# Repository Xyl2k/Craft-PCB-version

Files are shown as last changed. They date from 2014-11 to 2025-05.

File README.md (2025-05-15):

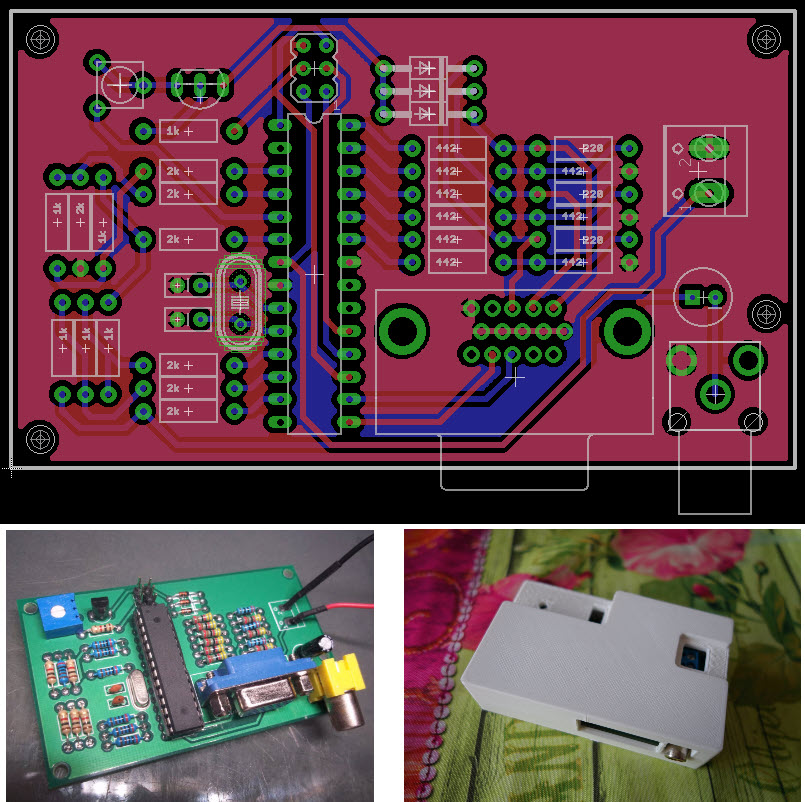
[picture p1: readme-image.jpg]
Craft


# CRAFT AVR Demo — Custom PCB and 3D Enclosure

This repository contains a custom **double-layer PCB** design and a **3D-printable enclosure** for running the [CRAFT demo](http://www.linusakesson.net/scene/craft/) by Linus Åkesson on an **ATmega88-20PU** microcontroller.

The project is developed in **Autodesk EAGLE** for the PCB layout and includes an **STL enclosure model** designed for FDM 3D printing.

---

## 📦 Contents

- `eagle/`: EAGLE schematic (`.sch`) and board layout (`.brd`)
- `enclosure/`: 3D enclosure model (`.stl`)
- `firmware/`: Precompiled HEX file and Flipper Zero-compatible firmware folder
- `README.md`: Project documentation

---

## ⚙️ Features

- Runs the original CRAFT demo at **20 MHz**
- Audio synthesized in real-time by the ATmega88
- Double-layer PCB with clear silkscreen labeling
- Compact size with mounting holes for enclosure
- Powered via ISP header or screw terminal in 3.3 volts

---

## 📋 Bill of Materials (BOM)

| Qty | Component | Value/Type |
|-----|---|---|
| x7  | Resistor | 2 kΩ |
| x6  | Resistor | 1 kΩ |
| x9  | Resistor | 442 Ω |
| x3  | Resistor | 220 Ω |
| x2  | Capacitor | 22 pF |
| x1  | Capacitor | 10 µF |
| x3  | Diode | 1N4148 |
| x1  | Transistor | BC560C |
| x1  | Trimmer Potentiometer  | 1 kΩ |
| x1  | Microcontroller | ATmega88-20PU |
| x1  | Crystal Oscillator | 20 MHz |
| x1  | VGA Socket (Female) | Through-hole |
| x1  | RCA Socket (Female) | Through-hole |
| x1  | Screw Terminal | 2-pin |

---

## 🖨️ Enclosure

- Format: `.stl` for 3D printing
- Designed for FDM printers (0.4 mm nozzle recommended)
- Includes cutouts for VGA, RCA, power terminal, and ISP pins
- Snap-fit
- PCB enclosure case.STL need to be printed with support.

---

## 🛠️ Flashing the Firmware

The `firmware/` folder includes:

- `flash.hex` — Precompiled firmware for ATmega88-20PU
- `AVR Flasher/` — Folder structure compatible with **Flipper Zero**

### 🔧 Flashing with Flipper Zero

1. Copy the content of `AVR Flasher/` folder to your Flipper Zero's SD card in (`/apps_data/avr_isp/`).
2. Connect your Flipper to the CRAFT PCB via the ISP header.
3. Open the [**AVR Flasher**](https://lab.flipper.net/apps/avr_isp) app on your Flipper.
4. Select Craft_pcb.avr firmware and flash it directly to the ATmega88.

---

## 🧠 Credits

- **Original CRAFT demo** by [Linus Åkesson](http://www.linusakesson.net/)
- **PCB and enclosure design** by myself for my hackerspace.

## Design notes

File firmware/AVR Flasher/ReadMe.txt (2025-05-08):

If you have a flipper zero you can simply download this app: https://lab.flipper.net/apps/avr_isp
Then drop in your SD card into folder: apps_data/avr_isp
- Craft_pcb.avr
- Craft_pcb_eeprom.hex
- Craft_pcb_flash.hex

Connect your flipper zero gpio to the SPI bus on the PCB and flash the ATMega88 using the app.

       FLIPPER ZERO --- PCB ---               PCB --- FLIPPER ZERO
                                  ______
          PIN 11  --  GND -----  | x  x |  ----> RST  -- PIN 06
          PIN 02  --  MOSI <---  | x  x    ----> SCK  -- PIN 05
          PIN 09  --  VCC -----  | x  x |  <---- MISO -- PIN 03
                                  ------

                                .---__---.     
                          RESET |        | PC5 
                                |        |     
                            PD0 |        | PC4 
                                |        |     
                            PD1 |        | PC3 
                                |        |     
                            PD2 |        | PC2 
                                |        |     
                           OC2B |        | PC1 
                                |        |     
                            PD4 |        | PC0 
                                |        |     
                            VCC |        | GND 
                                |        |     
                            GND |        | AREF
                                |        |     
                          XTAL1 |        | AVCC
                                |        |     
                          XTAL2 |        | SCK 
                                |        |     
                            PD5 |        | MISO
                                |        |     
                            PD6 |        | MOSI
                                |        |
                            PD7 |        | OC1B
                                |        |
                            PB0 |        | PB1 
                                `--------'

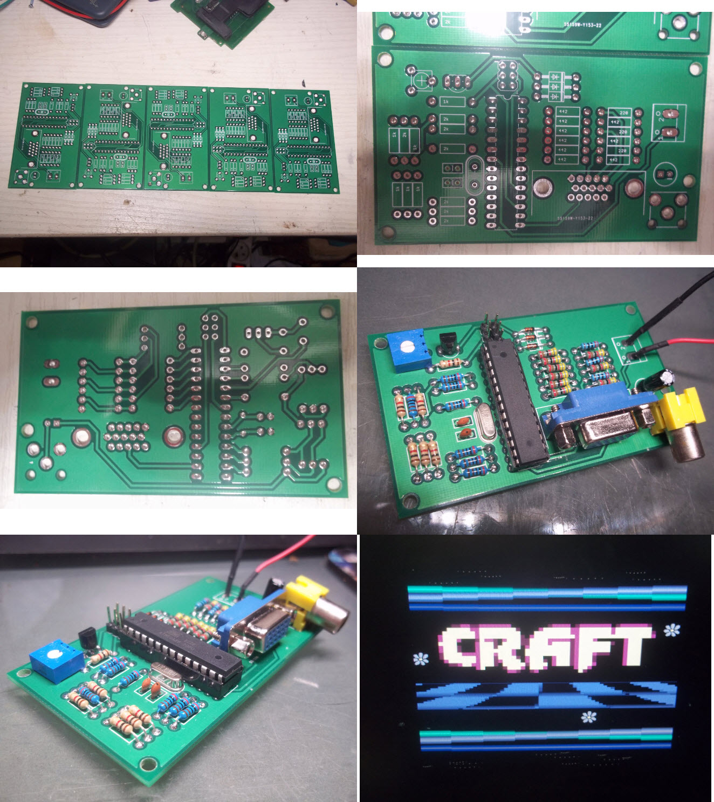
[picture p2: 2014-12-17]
PCB.jpg

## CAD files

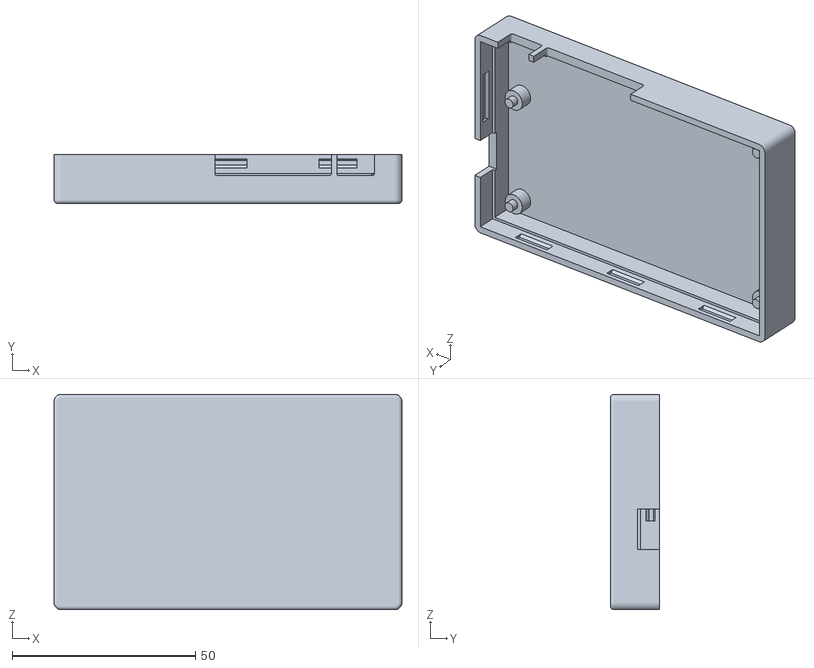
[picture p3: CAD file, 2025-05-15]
enclosure/PCB enclosure base.STL
95.1 x 13.4 x 58.9

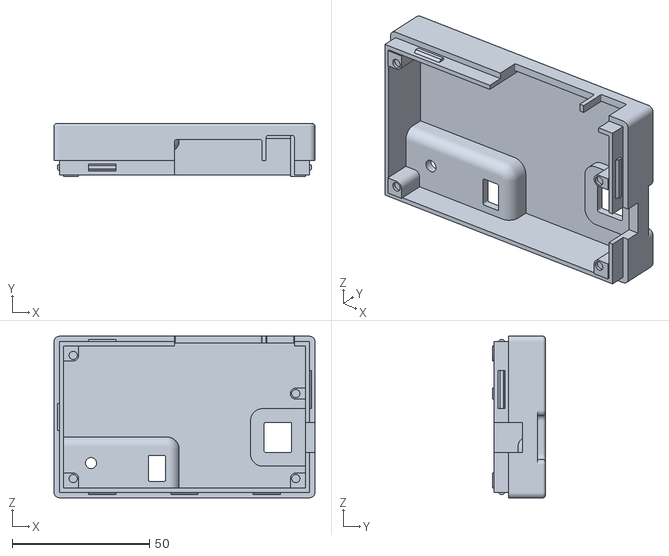
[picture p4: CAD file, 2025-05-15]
enclosure/PCB enclosure case.STL
95.1 x 19.3 x 58.9

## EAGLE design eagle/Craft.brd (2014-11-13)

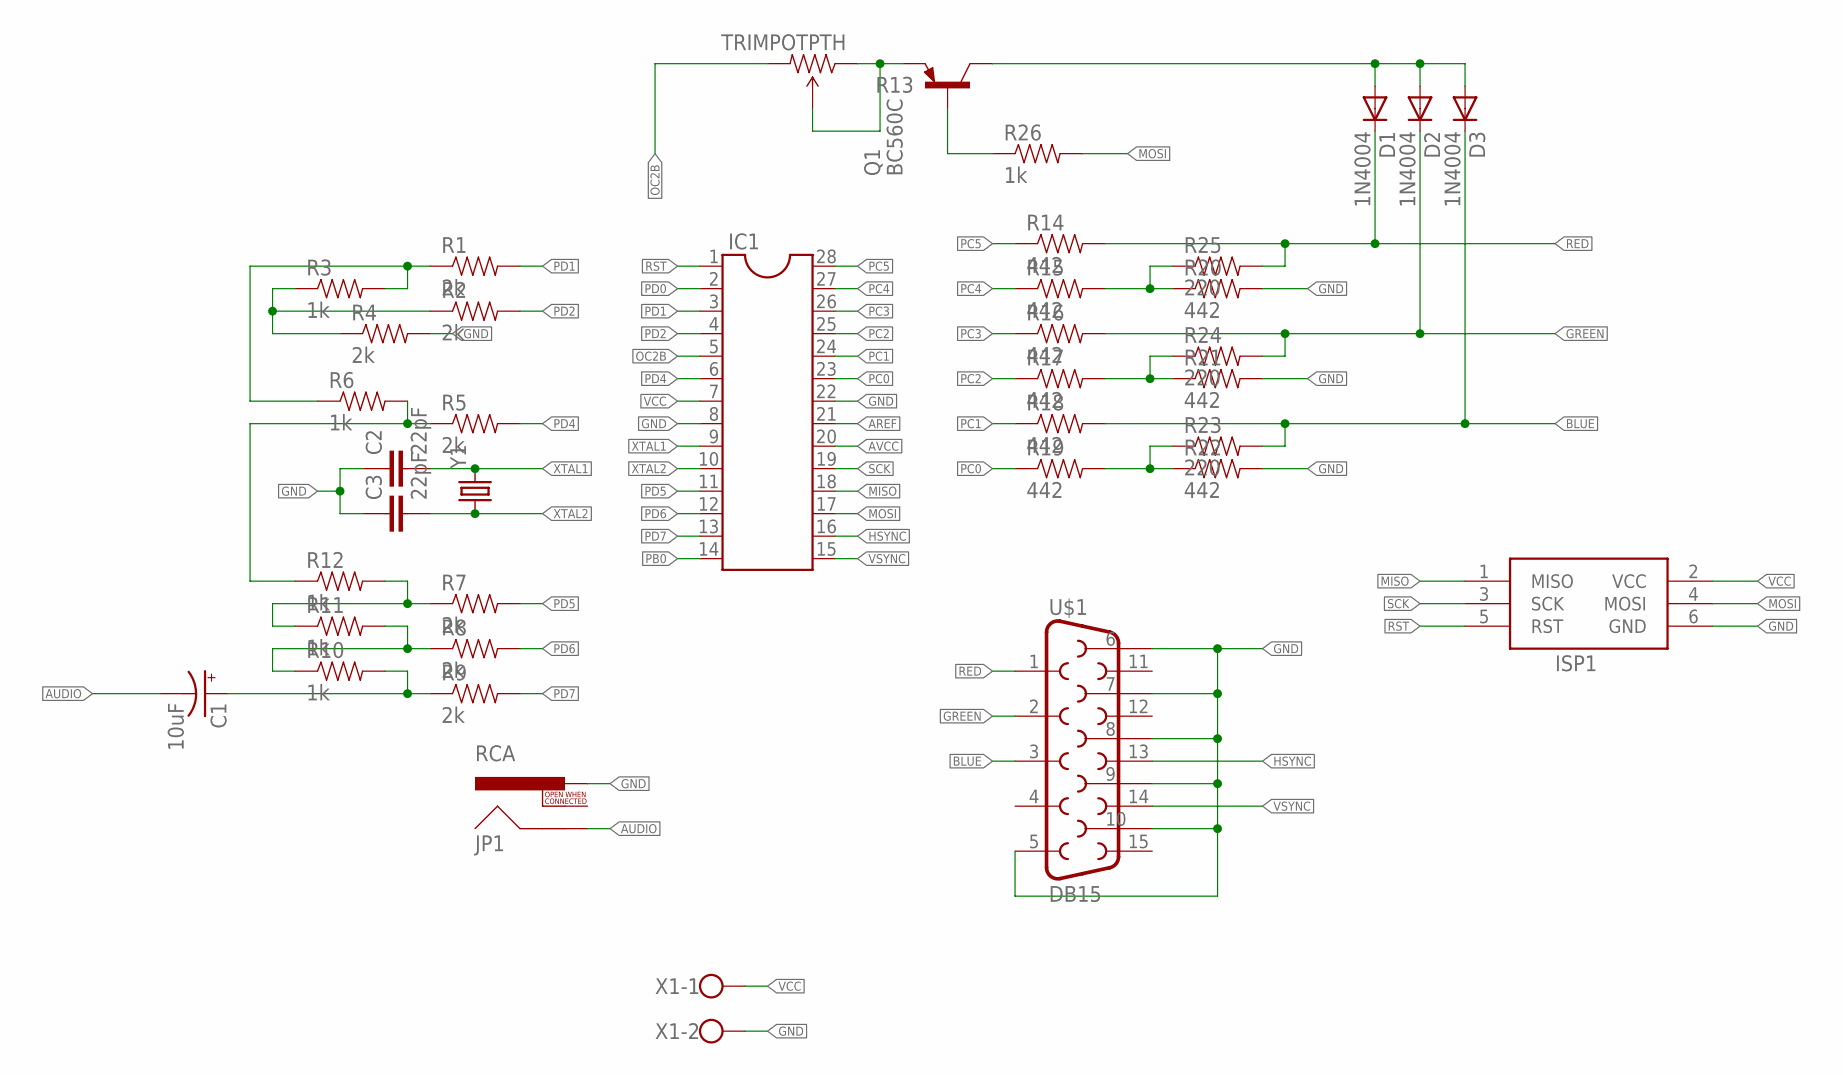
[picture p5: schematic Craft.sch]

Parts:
C1: 10uF; CPOL-RADIAL-100UF-25V
C2, C3: 22pF; CAP-PTH-SMALLEZ
D1, D2, D3: 1N4004; DO41-10
IC1: DIL28-3
ISP1: AVRISP-6; AVRISP
JP1: RCA
Q1: BC560C; TO92-EBC
R1, R2, R4, R5, R7, R8, R9: 2k; AXIAL-0.4
R3, R6, R10, R11, R12, R26: 1k; AXIAL-0.4
R13: TRIMPOTPTH; TRIM_POT_PTH
R14, R15, R16, R17, R18, R19, R20, R21, R22: 442; AXIAL-0.4
R23, R24, R25: 220; AXIAL-0.4
U$1: DB15
X1: W237-102
Y1: CRYSTALHC49UV; HC49U-V

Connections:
AREF: IC1.21
AUDIO: C1.2 (-), JP1.SHELL
AVCC: IC1.20
BLUE: D3.C, R18.P$2 (2), R23.P$2 (2), U$1.3
GND: C2.1, C3.1, IC1.8, IC1.22, ISP1.6 (GND), JP1.PIN, R4.P$2 (2), R20.P$2 (2), R21.P$2 (2), R22.P$2 (2), U$1.5, U$1.6, U$1.7, U$1.8, U$1.9, U$1.10, X1.2
GREEN: D2.C, R16.P$2 (2), R24.P$2 (2), U$1.2
HSYNC: IC1.16, U$1.13
MISO: IC1.18, ISP1.1 (MISO)
MOSI: IC1.17, ISP1.4 (MOSI), R26.P$2 (2)
unnamed: Q1.E, R13.1 (CCW), R13.2 (WIPER)
unnamed: D1.A, D2.A, D3.A, Q1.C
unnamed: Q1.B, R26.P$1 (1)
unnamed: R1.P$1 (1), R3.P$2 (2), R6.P$1 (1)
unnamed: R5.P$1 (1), R6.P$2 (2), R12.P$1 (1)
unnamed: R2.P$1 (1), R3.P$1 (1), R4.P$1 (1)
unnamed: C1.1 (+), R9.P$1 (1), R10.P$2 (2)
unnamed: R8.P$1 (1), R10.P$1 (1), R11.P$2 (2)
unnamed: R7.P$1 (1), R11.P$1 (1), R12.P$2 (2)
unnamed: R15.P$2 (2), R20.P$1 (1), R25.P$1 (1)
unnamed: R17.P$2 (2), R21.P$1 (1), R24.P$1 (1)
unnamed: R19.P$2 (2), R22.P$1 (1), R23.P$1 (1)
OC2B: IC1.5, R13.3 (CW)
PB0: IC1.14
PC0: IC1.23, R19.P$1 (1)
PC1: IC1.24, R18.P$1 (1)
PC2: IC1.25, R17.P$1 (1)
PC3: IC1.26, R16.P$1 (1)
PC4: IC1.27, R15.P$1 (1)
PC5: IC1.28, R14.P$1 (1)
PD0: IC1.2
PD1: IC1.3, R1.P$2 (2)
PD2: IC1.4, R2.P$2 (2)
PD4: IC1.6, R5.P$2 (2)
PD5: IC1.11, R7.P$2 (2)
PD6: IC1.12, R8.P$2 (2)
PD7: IC1.13, R9.P$2 (2)
RED: D1.C, R14.P$2 (2), R25.P$2 (2), U$1.1
RST: IC1.1, ISP1.5 (RST)
SCK: IC1.19, ISP1.3 (SCK)
VCC: IC1.7, ISP1.2 (VCC), X1.1
VSYNC: IC1.15, U$1.14
XTAL1: C2.2, IC1.9, Y1.2
XTAL2: C3.2, IC1.10, Y1.1

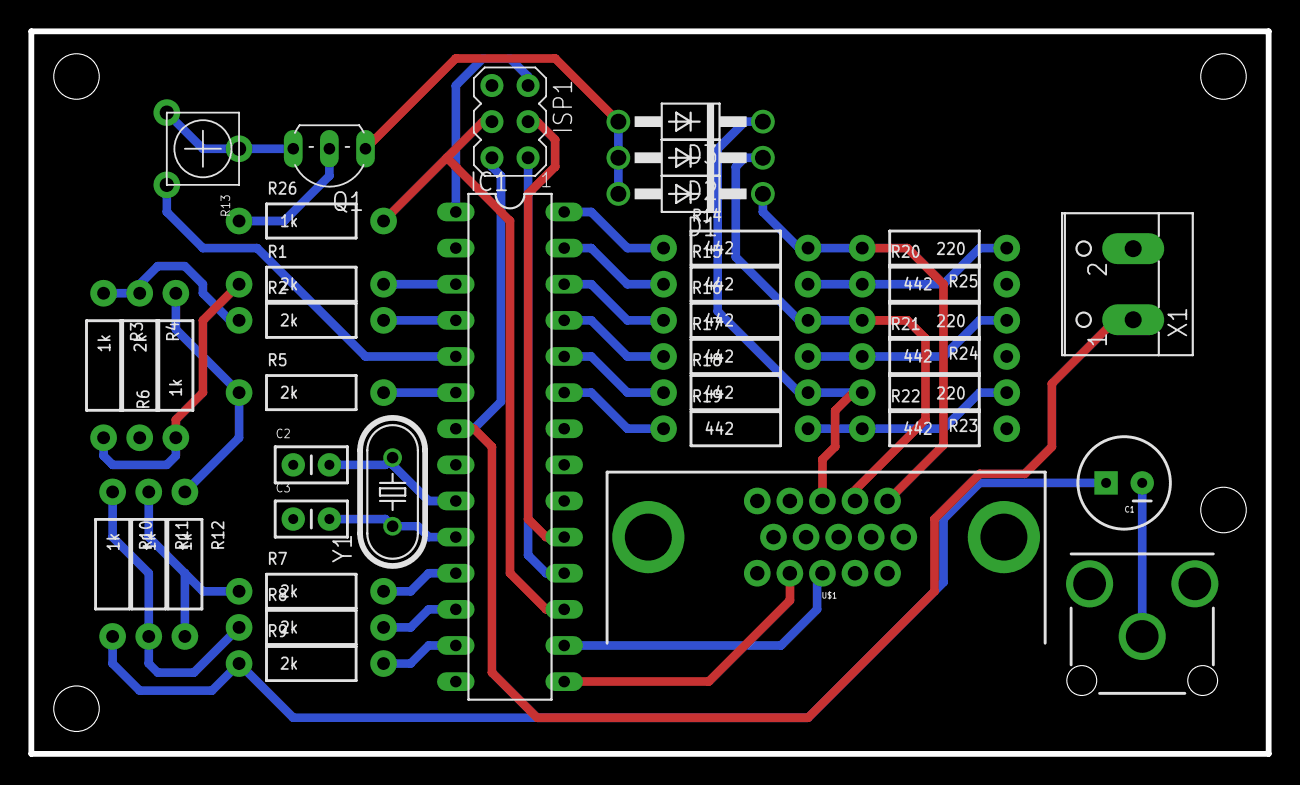
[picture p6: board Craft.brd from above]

Board: 2 copper layers, 87.0 x 50.8 mm, 39 parts (0 on the bottom side), 39 nets.

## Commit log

2014-11-13 v1.0
    v1.0 not tested
    [Craft.brd, Craft.sch]
2014-12-17 pcb working
    just a small problem with the alimentation but i've you power it up from
    programation pin there is no problem, demmo is running.
    Don't forget to set the fuses correctly and select: Ext. Full-swing
    Crystal; Start-up time PWRDWN/RESET: 16K CK/14 CK + 65 ms
    for the raw eeprom image: avrdude -c usbtiny -p m88 -U
    eeprom:w:eeprom.raw
2025-05-15 Update round
    Update round
    [Craft.brd, Craft.sch, PCB enclosure base.STL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]

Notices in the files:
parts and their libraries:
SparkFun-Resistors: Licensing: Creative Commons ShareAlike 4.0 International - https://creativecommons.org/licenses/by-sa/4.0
